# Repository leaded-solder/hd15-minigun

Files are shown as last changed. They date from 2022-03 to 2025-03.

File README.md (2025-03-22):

This is a version of the [Minigun Supergun](https://www.arcade-projects.com/threads/minigun-supergun-an-open-source-supergun.9408/) open-source supergun that supports HD15 ("VGA") output directly.

## Is it HD15 or VGA?
Technically, the signal being output is not compliant with VGA.

You will need a monitor that supports:
 - 15kHz or 24kHz horizontal sync input (depending on arcade board)
 - Combined sync on the horizontal sync pin

## Monitor compatibility
Tested with:
 - NEC MultiSync 3D CRT

## Version History
### v2
 - Fixed headphone jack with bad footprint
 - Connected HD15 shield to ground
 - Fixed transposed blue and green lines on HD15 connector

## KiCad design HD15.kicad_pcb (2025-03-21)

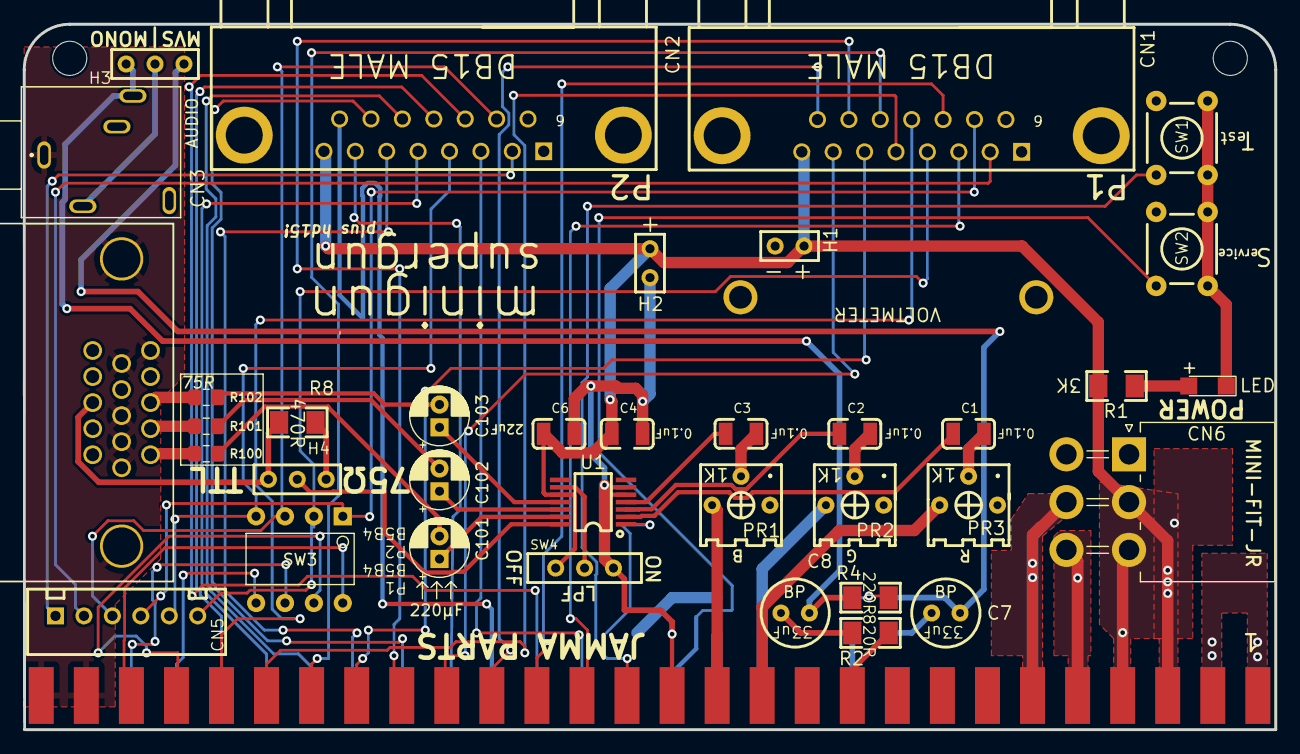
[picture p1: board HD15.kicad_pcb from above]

Board: 2 copper layers, 110.0 x 62.0 mm, 43 parts (0 on the bottom side), 64 nets.

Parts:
C1, C2, C3, C4, C5, C6: CAPACITOR 1206; CAP_1206
C7, C8: BP; CAPACITOR - TH - 2.5MM PITCH - 6MM ROUND - BP
C101, C102, C103: CP_Radial_D5.0mm_P2.00mm
CN1, CN2: 9; DB15-G-DC
CN3: 35RAPC4BH3; SWITCHCRAFT_35RAPC4BH3
CN5: B6B-XH-A(LF)(SN); JST_XH_6P - B6B-XH-A
CN6: 353180620; MOLEX_MINIFIT-JR-5569-06A2_2X03X4.20MM_ANGLED
H1, H2: HEADER - 2 PIN
H3: HEADER - 3 PIN; 3 PIN HEADER
H4: SYNC; 3 PIN HEADER
J1A, J1B: JAMMA PINS 3.96MM PITCH 2.2MM X 5MM
LED: LED 1206; LED_1206
PR1, PR2, PR3: 3362P-1-102LF; RES-ADJ_3362P
R1, R2, R3, R4, R5, R6, R7, R8: RESISTOR 1206; 1206
R100, R101, R102: R_0805_2012Metric_Pad1.15x1.40mm_HandSolder
SW1, SW2: MJTP1230; TACTILE-PTH
SW3: DIPSwitch-4
SW4: CL-SA-12C-02
U1: THS7374; TSSOP-14
VOLTMETER: VOLTMETER - SEED STUDIO

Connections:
+5V: C4.1, C6.1, CN1.8, CN2.8, CN6.2, CN6.3, H1.2, H2.2, J1A.25, J1A.26, J1B.3, J1B.4, R1.1, SW4.1, U1.10
+12V: CN6.5, J1A.23, J1B.6
-5V: CN6.6, J1A.24, J1B.5
AUDIO: CN3.5, H3.2
GND: C4.2, C6.2, CN1.0, CN1.1, CN2.0, CN2.1, CN3.1, CN6.1, CN6.4, H1.1, H2.1, J1A.1, J1A.2, J1A.15, J1A.27, J1A.28, J1B.1, J1B.2, J1B.27, J1B.28, LED.1, PR1.3, PR2.3, PR3.3, R4.2, R5.2, R7.1, SW1.1, SW1.2, SW2.1, SW2.2, SW4.3, U1.5, U1.6
LED: LED.2, R1.2
LPF: SW4.2, U1.9
P1_B1: CN1.13, J1A.7
P1_B2: CN1.5, J1A.6
P1_B3: CN1.12, J1A.5
P1_B4: CN1.4, CN5.6, SW3.2
P1_B4_J: J1A.4, SW3.7
P1_B5: CN1.10, CN5.4, SW3.1
P1_B5_J: J1A.3, SW3.8
P1_B6: CN1.2, CN5.2
P1_COIN: CN1.3, J1A.13
P1_DOWN: CN1.7, J1A.10
P1_LEFT: CN1.14, J1A.9
P1_RIGHT: CN1.6, J1A.8
P1_START: CN1.11, J1A.12
P1_UP: CN1.15, J1A.11
P2_B1: CN2.13, J1B.22
P2_B2: CN2.5, J1B.23
P2_B3: CN2.12, J1B.24
P2_B4: CN2.4, CN5.5, SW3.4
P2_B4_J: J1B.25, SW3.5
P2_B5: CN2.10, CN5.3, SW3.3
P2_B5_J: J1B.26, SW3.6
P2_B6: CN2.2, CN5.1
P2_COIN: CN2.3, J1B.16
P2_DOWN: CN2.7, J1B.19
P2_LEFT: CN2.14, J1B.20
P2_RIGHT: CN2.6, J1B.21
P2_START: CN2.11, J1B.17
P2_UP: CN2.15, J1B.18
SP+_1: J1A.19, R2.2
SP+_2: C8.1, R2.1
SP+_3: C8.2, CN3.2, H3.1, R4.1
SP-_1: J1B.10, R3.2
SP-_2: C7.1, R3.1
SP-_3: C7.2, H3.3, R5.1
SW_SERVICE: J1B.14, SW2.4
SW_TEST: J1A.14, SW1.4
VIDEO_BLUE: J1A.16, PR1.1
VIDEO_BLUE_1: C3.2, PR1.2
VIDEO_BLUE_2: C3.1, U1.4
VIDEO_BLUE_3: C103.1, U1.11
VIDEO_BLUE_4: C103.2, R102.2
VIDEO_GREEN: J1B.12, PR2.1
VIDEO_GREEN_1: C2.2, PR2.2
VIDEO_GREEN_2: C2.1, U1.3
VIDEO_GREEN_3: C102.1, U1.12
VIDEO_GREEN_4: C102.2, R101.2
VIDEO_RED: J1A.17, PR3.1
VIDEO_RED_1: C1.2, PR3.2
VIDEO_RED_2: C1.1, U1.2
VIDEO_RED_3: C101.1, U1.13
VIDEO_RED_4: C101.2, R100.2
VIDEO_SYNC: J1B.13, R6.2
VIDEO_SYNC_1: C5.2, R6.1, R7.2
VIDEO_SYNC_1A: C5.1, U1.1
VIDEO_SYNC_3: H4.2, U1.14
VIDEO_SYNC_4: H4.3, R8.2
VIDEO_SYNC_5: H4.1, R8.1

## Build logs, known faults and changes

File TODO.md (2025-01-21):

 - [x] coupling caps for r, g, b?
 - [x] series 75 ohm for r, g, b?
 - [x] fix headphone jack

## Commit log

2022-03-12 Initial VGA placement, still need to find somewhere for the audio jack
    [MDIN9.kicad_pcb]
2022-03-12 Full route
    [MDIN9.kicad_pcb]
2022-03-13 Decoupling caps for R, G, B
    [MDIN9.kicad_pcb]
2022-03-13 Coupling caps, series resistors for rgb
    [MDIN9.kicad_pcb]
2022-03-13 Send v0.2 to fab
    [MDIN9.kicad_pcb]
2022-03-14 Mounting holes down to 2.0mm
    [HD15.kicad_pcb]
2022-03-14 Convert to KiCad 6
    [HD15.kicad_pcb]
2022-03-14 Complete kicad6 conversion
2022-03-28 Fix 5V pour on obverse
    [HD15.kicad_pcb]
2025-01-21 Fix rotated hole in headphone jack
    [HD15.kicad_pcb]
2025-03-21 Fix RBG -> RGB screwup
    [HD15.kicad_pcb]
2025-03-21 Make 75 ohm option obviously preferable
    [HD15.kicad_pcb]
2025-03-21 General label cleanup
    [HD15.kicad_pcb]
2025-03-21 Connect VGA shield to logic ground
    [HD15.kicad_pcb]

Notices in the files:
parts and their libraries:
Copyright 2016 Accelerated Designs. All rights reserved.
